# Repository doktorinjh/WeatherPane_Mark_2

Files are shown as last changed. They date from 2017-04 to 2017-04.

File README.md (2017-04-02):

# WeatherPane Mark 2
A new variation on the WeatherPane that has an antique look and uses stepper motors to point to the weather forecast. Pictures and a semi-build log are here: http://imgur.com/a/7An7O

WeatherPane v2
Created May 1st, 2016

This sketch will run three 28YBJ-48 stepper motors to point to weather data
obtained from the Weather Underground and displayed on a clock-like face.
The stepper motors are initialized after each update to make sure
that the pointers are reasonably accurate. The home condition
is established using hall sensors on the analog data pins. There are magnets imbedded in the
3D printed hands that trip the sensor. 

Data collected from WU includes the current weather condition, current
temperature, and current chance of precipitation.

Contact me with any questions, updates, or pictures of your own: doktorinjh@gmail.com

This code is not licensed or approved for commercial use and may not be replicated
without contacting the creator.
 
Change Log:
 * 6/16/16 - Changed stuff back, change all ints to double
 * 6/14/16 - Commented out Stepper.h and MemoryFree.h, changed Pins to #define, lowered char counts, commented out serial and console prints
 * 6/11/16 - Changed Double to Int for steppers
 * 5/29/16 - Moved scripts to WeatherPaneScripts instead of SD card
 * 5/27/16 - Removed millis for time, added MemoryFree for leak check
 
# Install
There are 3 files that you'll need to get started and maybe the additional stepper motor libraries? You will also need a WeatherUnderground API Key and insert that into Line 5 of the Bridge file. More WU API info is here: https://www.wunderground.com/weather/api/d/docs?MR=1

# 3D Print Files
There are several files for 3D printing the hands, hand shafts, and mounting blocks. I've included some hand variations, too. 

# Face Plate
There are some instructions in the build album that show how to get the face plate onto the pine board. You'll need some paint, modge podge, a reverse printed image, and patience. 

# Known Problems
I have had issues with the Bridge on the Yun freezing up and the whole system requires a reboot. If anyone figures it out, please let me know. This sketch isn't as clean as I'd like it, but it has been sitting on my shelf for too long and I wanted to share it. The MemoryFree library was left in because I was using that to try and diagnose the Bridge shutdown issue.

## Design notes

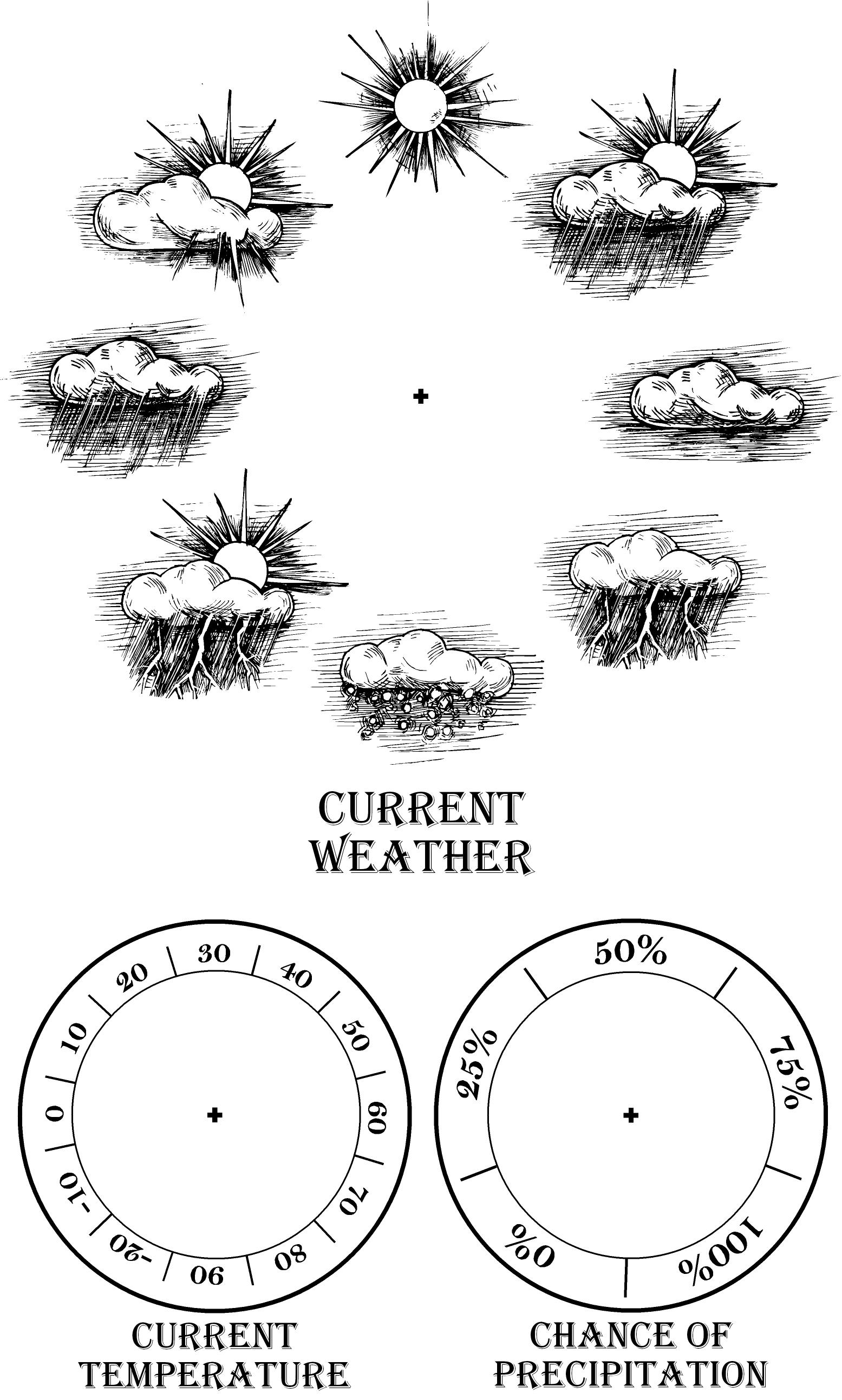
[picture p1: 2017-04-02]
Faceplate Design.jpg

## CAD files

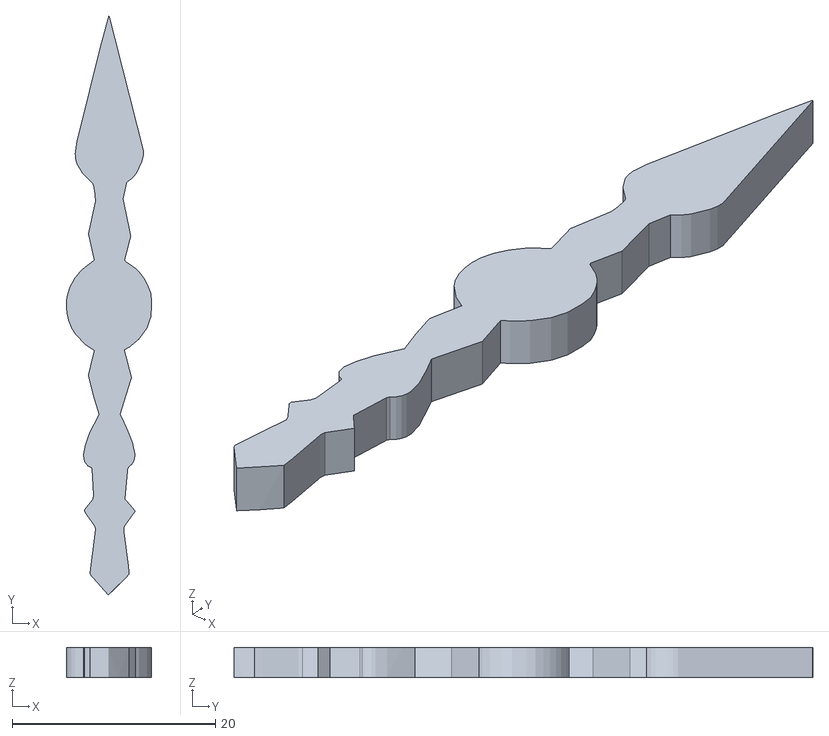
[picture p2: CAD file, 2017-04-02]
Skinny Hand.stl
8.40 x 57.0 x 3.00

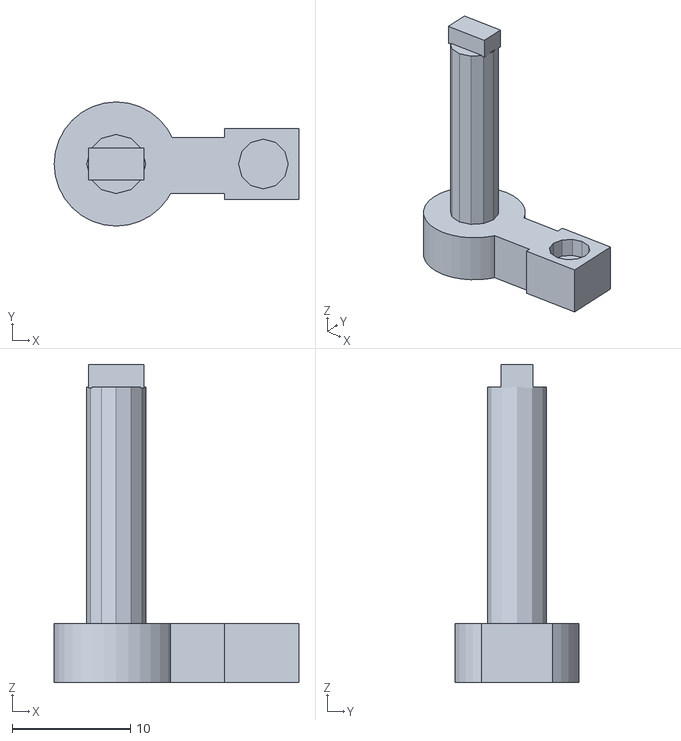
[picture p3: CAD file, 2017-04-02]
28byj-48 short shaft extension v2.stl
20.7 x 10.5 x 26.9

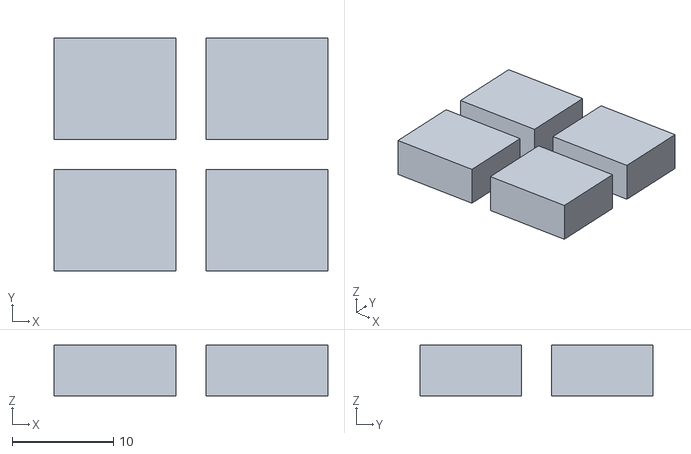
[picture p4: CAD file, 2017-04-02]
Motor Blocks 12mm x 4.stl
27.0 x 23.0 x 5.00

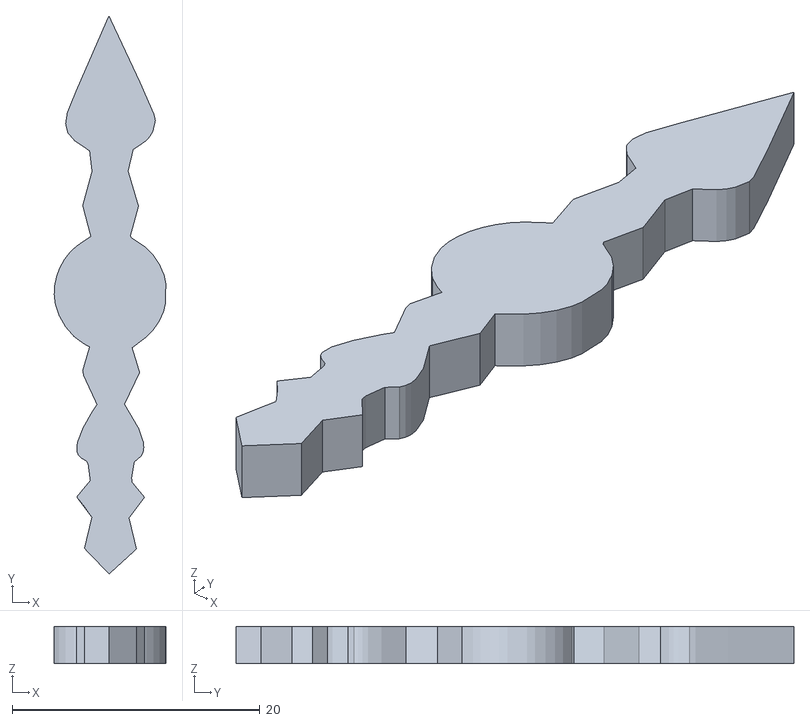
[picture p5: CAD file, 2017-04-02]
Small_hands.stl
9.00 x 45.0 x 3.00

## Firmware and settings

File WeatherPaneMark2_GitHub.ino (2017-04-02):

/* WeatherPane v2
 * Created May 1st, 2016
 * www.weatherpane.net
 *
 * This sketch will run three 28YBJ-48 stepper motors to point to weather data
 * obtained from the Weather Underground and displayed on a clock-like face.
 * The stepper motors are initialized after each update to make sure
 * that the pointers are reasonably accurate. The home condition
 * is established using hall sensors on the analog data pins.
 *
 * Data collected from WU includes the current weather condition, current
 * temperature, and current chance of precipitation.
 *
 * Contact me with any questions or updates: info@weatherpane.net or doktorinjh@gmail.com
 *
 * This code is not licensed or approved for commercial use and may not be replicated
 * without contacting the creator.
 * 
 * Change Log:
 * 6/16/16 - Changed stuff back, change all ints to double
 * 6/14/16 - Commented out Stepper.h and MemoryFree.h, changed Pins to #define, lowered char counts, commented out serial and console prints
 * 6/11/16 - Changed Double to Int for steppers
 * 5/29/16 - Moved scripts to WeatherPaneScripts instead of SD card
 * 5/27/16 - Removed millis for time, added MemoryFree for leak check
 * 
 */

//#include <Stepper.h>                                              // Include Libraries
#include <Process.h>
#include <Bridge.h>
#include <AccelStepper.h>
#include <MultiStepper.h>
#include <MemoryFree.h>

MultiStepper steppers;

//#define IconPin A0                                           // Analog pin for the Icon Hall Sensor
//#define TempPin A1                                           // Analog pin for the Temp Hall Sensor
//#define PrecipPin A2                                         // Analog pin for the Precip Hall Sensor
const int IconPin = A0;                                           // Analog pin for the Icon Hall Sensor
const int TempPin = A1;                                           // Analog pin for the Temp Hall Sensor
const int PrecipPin = A2;                                         // Analog pin for the Precip Hall Sensor

double IconCurrent = 1000;                                        // Initilize variable for Icon Hall Sensor
double TempCurrent = 1000;                                        // Initilize variable for Temp Hall Sensor
double PrecipCurrent = 1000;                                      // Initilize variable for Precip Hall Sensor
//int IconCurrent = 1000;                                           // Initilize variable for Icon Hall Sensor
//int TempCurrent = 1000;                                           // Initilize variable for Temp Hall Sensor
//int PrecipCurrent = 1000;                                         // Initilize variable for Precip Hall Sensor

const int IconCorrection = 40;                                    // If Icon Hall Sensor isn't 0 degrees, adjust here
const int TempCorrection = 110;                                   // If Temp Hall Sensor isn't 0 degrees, adjust here
const int PrecipCorrection = 80;                                  // If Precip Hall Sensor isn't 0 degrees, adjust here

char location[30];                                                // Variables for location and update time
char update_time[45];

char current_temp[7];                                            // Variables for current conditions
char current_weather[30];
char current_precip[7];

#define STEPS 200                                                 // Define Steps for motor, not sure if needed
//Stepper icon_stepper(STEPS, 2, 4, 3, 5);                          // Setup Icon motor for 4-wire on pins 2-5
//Stepper temp_stepper(STEPS, 6, 8, 7, 9);                          // Setup Temp motor for 4-wire on pins 6-9
//Stepper precip_stepper(STEPS, 10, 12, 11, 13);                    // Setup Precip motor for 4-wire on pins 10-13

AccelStepper icon_accel(4, 2, 4, 3, 5);                           // Setup Icon motor for 4-wire on pins 2-5
AccelStepper temp_accel(4, 6, 8, 7, 9);                           // Setup Temp motor for 4-wire on pins 6-9
AccelStepper precip_accel(4, 10, 12, 11, 13);                     // Setup Precip motor for 4-wire on pins 10-13

//unsigned long interval = 600000;                                  // Wait 10 minutes to update

long positions[3];

double freeRam()
//int freeRam () 
{
  extern int __heap_start, *__brkval; 
  int v; 
  return (int) &v - (__brkval == 0 ? (int) &__heap_start : (int) __brkval); 
}

void setup() {
  icon_accel.setMaxSpeed(500.0);                                  // AccelStepper setup for the 3 motors
  icon_accel.setAcceleration(1000.0);
  temp_accel.setMaxSpeed(500.0);
  temp_accel.setAcceleration(1000.0);
  precip_accel.setMaxSpeed(500.0);
  precip_accel.setAcceleration(1000.0);

  steppers.addStepper(icon_accel);                                // Add Multistepper motors
  steppers.addStepper(temp_accel);
  steppers.addStepper(precip_accel);
  
  Initialize();                                                   // Get the steppers to their homes

  double current_temp_int = atoi(current_temp);                      // Convert values to integers
  double current_precip_int = atoi(current_precip);        
  //int current_temp_int = atoi(current_temp);                      // Convert values to integers
  //int current_precip_int = atoi(current_precip);
  
  Bridge.begin();                                                 // Begin Bridge
  //Console.begin();                                                // Begin Console
  delay(5000);
  //Console.println(freeRam());

  Process bridge;                                                 // Get intitial values from the bridge
  bridge.runShellCommand("python /WeatherPaneScripts/WU_Bridge.py");

  Process variables;                                              // Get the variables
  variables.runShellCommand("python /WeatherPaneScripts/WU_Variables.py");

  Bridge.get("current_temp", current_temp, 7);                    // Get variables and convert to integers
  Bridge.get("current_weather", current_weather, 30);
  Bridge.get("current_precip", current_precip, 7);
  Bridge.get("location", location, 30);
  Bridge.get("time", update_time, 45);

  current_temp_int = atoi(current_temp);                          // Convert values to integers
  current_precip_int = atoi(current_precip);
  
  //Console.println(freeMemory());
  //ConsolePrint();

  Condition(current_weather);                                     // Display current weather condition
  Temperature(current_temp_int);                                  // Display current temperature
  Precipitation(current_precip_int);                              // Display current chance of precip
      steppers.moveTo(positions);                                 // MultiStepper move
      steppers.runSpeedToPosition();
  stopmotor();
}


void loop() {
  
    Process bridge;                                               // Get intitial values from the bridge
    bridge.runShellCommand("python /WeatherPaneScripts/WU_Bridge.py");

    Process variables;                                            // Get the variables
    variables.runShellCommand("python /WeatherPaneScripts/WU_Variables.py");
    
    Bridge.get("current_temp", current_temp, 7);                  // Get variables and convert to integers
    Bridge.get("current_weather", current_weather, 30);
    Bridge.get("current_precip", current_precip, 7);
    Bridge.get("location", location, 30);
    Bridge.get("time", update_time, 45);

    double current_temp_int = atoi(current_temp);                      // Convert values to integers
    double current_precip_int = atoi(current_precip);
    //int current_temp_int = atoi(current_temp);                    // Convert values to integers
    //int current_precip_int = atoi(current_precip);

/////////////////////////////////////////////////////////////////////////////////////////////////////////////////
    Initialize();                                               // Find home (moves changes when commented out)
/////////////////////////////////////////////////////////////////////////////////////////////////////////////////
    //Console.println(freeMemory());        
    //ConsolePrint();

    Condition(current_weather);                                   // Display current weather condition
    Temperature(current_temp_int);                                // Display current temperature
    Precipitation(current_precip_int);                            // Display today's chance of precip
      steppers.moveTo(positions);                                 // MultiStepper move
      steppers.runSpeedToPosition();

    stopmotor();                                                  // Turn off motors
    delay(600000);
}


void Initialize() {
    Bridge.get("current_temp", current_temp, 7);                  
    Bridge.get("current_weather", current_weather, 30);
    Bridge.get("current_precip", current_precip, 7);

    double current_temp_int = atoi(current_temp);                      // Convert values to integers
    double current_precip_int = atoi(current_precip);
    //int current_temp_int = atoi(current_temp);                    
    //int current_precip_int = atoi(current_precip);

    IconCurrent = analogRead(IconPin);                            // Read the analog pin values
    TempCurrent = analogRead(TempPin);
    PrecipCurrent = analogRead(PrecipPin);

    if (IconCurrent < 600)  {                                     // Move the pointer away from the hall sensor
      icon_accel.move(500);}
    if (TempCurrent < 600)  {
      temp_accel.move(500);}
    if (PrecipCurrent < 600) {
      precip_accel.move(500); }
    while ((icon_accel.distanceToGo()!= 0)||
      (temp_accel.distanceToGo()!= 0)||
        (precip_accel.distanceToGo()!= 0)){
      icon_accel.run(); 
      temp_accel.run();
      precip_accel.run();}
  
  boolean iconHomed = false;
  boolean tempHomed = false;
  boolean precipHomed = false;
  
  icon_accel.setSpeed(500);                                       // Set speed for steppers
  temp_accel.setSpeed(500);
  precip_accel.setSpeed(500);

  while (!iconHomed || !tempHomed || !precipHomed) {              // While any one of the steppers are not homed
    if (!iconHomed) {                                             // Home Icon stepper
      IconCurrent = analogRead(IconPin);
      if (IconCurrent < 600) {                                    // Home found
        iconHomed = true;
        icon_accel.moveTo(icon_accel.currentPosition());          // Zero the target
        icon_accel.setSpeed(0);}                                  // Set speed to 0 to prevent movement
    }

    if (!tempHomed) {                                             // Home the Temp stepper
      TempCurrent = analogRead(TempPin);
      if (TempCurrent < 600) {
        tempHomed = true;
        temp_accel.moveTo(temp_accel.currentPosition());
        temp_accel.setSpeed(0);}
    }

    if (!precipHomed) {                                           // Home the Precip stepper
      PrecipCurrent = analogRead(PrecipPin);
      if (PrecipCurrent < 600) {
        precipHomed = true;
        precip_accel.moveTo(precip_accel.currentPosition());
        precip_accel.setSpeed(0);}
    }
    
    icon_accel.runSpeed();                                        // Run if not home
    temp_accel.runSpeed();
    precip_accel.runSpeed();
  }
  
  icon_accel.move(IconCorrection);                                // Add correction to get to "real" 0
  temp_accel.move(TempCorrection);
  precip_accel.move(PrecipCorrection);
      while ((icon_accel.distanceToGo()!= 0)||
      (temp_accel.distanceToGo()!= 0)||
      (precip_accel.distanceToGo()!= 0)){
      icon_accel.run(); 
      temp_accel.run();
      precip_accel.run();}
  stopmotor();
  icon_accel.setCurrentPosition(0);
  temp_accel.setCurrentPosition(0);
  precip_accel.setCurrentPosition(0);

}


void stopmotor() {                                                // Turns off the Stepper Motors
  digitalWrite(2, LOW);                                           // Icon motor
  digitalWrite(3, LOW);
  digitalWrite(4, LOW);
  digitalWrite(5, LOW);

  digitalWrite(6, LOW);                                           // Temp motor
  digitalWrite(7, LOW);
  digitalWrite(8, LOW);
  digitalWrite(9, LOW);

  digitalWrite(10, LOW);                                          // Precipitation motor
  digitalWrite(11, LOW);
  digitalWrite(12, LOW);
  digitalWrite(13, LOW);
}

//void Temperature (int t) {                                        // Temperature Function
void Temperature (double t) {                                        // Temperature Function
  if (t < -22) {                                                  // -25 or less Degrees
    positions[1] = 1109; }
  if (t >= -22 && t < -18) {                                      // -20 Degrees
    positions[1] = 1195; }
  if ((t >= -18) && (t < -13)) {                                  // -15 Degrees
    positions[1] = 1280; }
  if ( (t >= -13) && (t < -8)) {                                  // -10 Degrees
    positions[1] = 1365; }
  if ( (t >= -8) && (t < -3)) {                                   // -5 Degrees
    positions[1] = 1451; }
  if ( (t >= -3) && (t < 3)) {                                    // 0 Degrees
    positions[1] = 1536; }
  if ( (t >= 3) && (t < 8)) {                                     // 5 Degrees
    positions[1] = 1621; }
  if ( (t >= 8) && (t < 13)) {                                    // 10 Degrees
    positions[1] = 1707; }
  if ( (t >= 13) && (t < 18)) {                                   // 15 Degrees
    positions[1] = 1792; }
  if ( (t >= 18) && (t < 23)) {                                   // 20 Degrees
    positions[1] = 1877; }
  if ( (t >= 23) && (t < 28)) {                                   // 25 Degrees
    positions[1] = 1963; }
  if ( (t >= 28) && (t < 33)) {                                   // 30 Degrees
    positions[1] = 2048; }
  if ( (t >= 33) && (t < 38)) {                                   // 35 Degrees
    positions[1] = 85; }
  if ( (t >= 38) && (t < 43)) {                                   // 40 Degrees
    positions[1] = 171; }
  if ( (t >= 43) && (t < 48)) {                                   // 45 Degrees
    positions[1] = 256; }
  if ( (t >= 48) && (t < 53)) {                                   // 50 Degrees
    positions[1] = 341; }
  if ( (t >= 53) && (t < 58)) {                                   // 55 Degrees
    positions[1] = 440; }
  if ( (t >= 58) && (t < 63)) {                                   // 60 Degrees
    positions[1] = 512; }
  if ( (t >= 63) && (t < 68)) {                                   // 65 Degrees
    positions[1] = 597; }
  if ( (t >= 68) && (t < 73)) {                                   // 70 Degrees
    positions[1] = 683; }
  if ( (t >= 73) && (t < 78)) {                                   // 75 Degrees
    positions[1] = 768; }
  if ( (t >= 78) && (t < 83)) {                                   // 80 Degrees
    positions[1] = 853; }
  if ( (t >= 83) && (t < 88)) {                                   // 85 Degrees
    positions[1] = 939; }
  if (t >= 88 && (t < 110)) {                                     // 90+ Degrees
    positions[1] = 1030; }
}

void Precipitation (double p) {                                      // Precipitation Function
//void Precipitation (int p) {                                      // Precipitation Function
  if ( (p >= 0) && (p < 10)); {                                   // 0% Chance
    positions[2] = 1229; }
  if ( (p >= 10) && (p < 35)) {                                   // 25% Chance
    positions[2] = 1638; }
  if ( (p >= 35) && (p < 65)) {                                   // 50% Chance
    positions[2] = 2048; } 
  if ( (p >= 65) && (p < 85)) {                                   // 75% Chance
    positions[2] = 370; }
  if ( (p >= 85) && (p < 110)) {                                  // 100% Chance
    positions[2] = 808; }
}


void Condition (char icon[]) {                                    // Weather Icon Functions, 25 in Total
  if (strcmp(icon, "Clear") == 0) {                               // Clear
    positions[0] = 2048; }
  if (strcmp(icon, "Cloudy") == 0) {                              // Cloudy
    positions[0] = 530; }
  if (strcmp(icon, "Partly Cloudy") == 0) {                       // Partly Cloudy
      positions[0] = 1792; }
  if (strcmp(icon, "Mostly Cloudy") == 0) {                       // Mostly Cloudy
    positions[0] = 530; }
  if (strcmp(icon, "Rain") == 0) {                                // Rain
    positions[0] = 1536; }
  if (strcmp(icon, "Snow") == 0) {                                // Snow
    positions[0] = 1024; }
  if (strcmp(icon, "Snow Showers") == 0) {                        // Snow Showers
    positions[0] = 1024; }
  if (strcmp(icon, "Thunderstorm") == 0) {                        // Thunderstorm
    positions[0] = 768; }
  if (strcmp(icon, "Overcast") == 0) {                            // Overcast
    positions[0] = 530; }
  if (strcmp(icon, "Chance of Rain") == 0) {                      // Chance of Rain
    positions[0] = 256; }
  if (strcmp(icon, "Chance of Thunderstorms") == 0) {             // Chance of Thunderstorms
    positions[0] = 1280; }
  if (strcmp(icon, "Chance of a Thunderstorm") == 0) {            // Chance of a Thunderstorm
    positions[0] = 1280; }
  if (strcmp(icon, "Chance of Flurries") == 0) {                  // Chance of Flurries
    positions[0] = 1024; }
  if (strcmp(icon, "Chance Rain") == 0) {                         // Chance Rain
    positions[0] = 1536; }
  if (strcmp(icon, "Chance of Freezing Rain") == 0) {             // Chance of Freezing Rain
    positions[0] = 1024; }
  if (strcmp(icon, "Chance of Sleet") == 0) {                     // Chance of Sleet
    positions[0] = 1024; }
  if (strcmp(icon, "Flurries") == 0) {                            // Flurries (not furries)
    positions[0] = 1024; }
  if (strcmp(icon, "Fog") == 0) {                                 // Fog
    positions[0] = 530; }
  if (strcmp(icon, "Haze") == 0) {                                // Haze
    positions[0] = 1792; }
  if (strcmp(icon, "Mostly Sunny") == 0) {                        // Mostly Sunny
    positions[0] = 1792; }
  if (strcmp(icon, "Partly Sunny") == 0) {                        // Partly Sunny
    positions[0] = 1792; }
  if (strcmp(icon, "Freezing Rain") == 0) {                       // Freezing Rain
    positions[0] = 1024; }
  if (strcmp(icon, "Sleet") == 0) {                               // Sleet
    positions[0] = 1024; }
  if (strcmp(icon, "Thunderstorms") == 0) {                       // Thunderstorms
    positions[0] = 768; }
  if (strcmp(icon, "Unknown") == 0) {                             // Unknown
    positions[0] = 1280; }
  if (strcmp(icon, "Scattered Clouds") == 0) {                    // Scattered Clouds
    positions[0] = 1792; }
  if (strcmp(icon, "Ice Pellets") == 0) {                         // Ice Pellets
    positions[0] = 1024; }
  if (strcmp(icon, "Chance of Snow") == 0) {                      // Chance of Snow
    positions[0] = 1024; }
  if (strcmp(icon, "") == 0)  {                                   // No Reading, also used during setup
    positions[0] = -768;  }
}

/*
void ConsolePrint() {                                             // Print weather to Console to check the data
  Bridge.get("current_temp", current_temp, 7);           
  Bridge.get("current_weather", current_weather, 30);
  Bridge.get("current_precip", current_precip, 7);
  Bridge.get("location", location, 30);
  Bridge.get("time", update_time, 45);

  double current_temp_int = atoi(current_temp);             
  double current_precip_int = atoi(current_precip);
  //int current_temp_int = atoi(current_temp);             
  //int current_precip_int = atoi(current_precip);

  Console.print("In ");
  Console.print(location);
  Console.print(", it is currently ");
  Console.print(current_temp_int);
  Console.print(" degrees out and ");
  Console.print(current_weather);
  Console.println(".");
  Console.print("There is a ");
  Console.print(current_precip_int);
  Console.println("% chance of precip at the moment.");
  Console.println(update_time);
  Console.println();
  Console.println(positions[0]);
  Console.println(positions[1]);
  Console.println(positions[2]);
//  Console.println(previousMillis);
  Console.println(freeMemory());
  Console.println(freeRam());
  Console.println();
}


void SerialPrint() {                                              // Print weather to Serial to check the data
  Bridge.get("current_temp", current_temp, 7);           
  Bridge.get("current_weather", current_weather, 30);
  Bridge.get("current_precip", current_precip, 7);
  Bridge.get("location", location, 30);
  Bridge.get("time", update_time, 45);

  int current_temp_int = atoi(current_temp);                  
  int current_precip_int = atoi(current_precip);

  Serial.print("In ");                                        
  Serial.print(location);
  Serial.print(", it is currently ");
  Serial.print(current_temp_int);
  Serial.print(" degrees out and ");
  Serial.print(current_weather);
  Serial.println(".");
  Serial.print("There is a ");
  Serial.print(current_precip_int);
  Serial.println("% chance of precip today.");
  Serial.println(update_time);
  Serial.println();
  Serial.println(positions[0]);
  Serial.println(positions[1]);
  Serial.println(positions[2]);
  Serial.println();
}
*/

/* Fin */
